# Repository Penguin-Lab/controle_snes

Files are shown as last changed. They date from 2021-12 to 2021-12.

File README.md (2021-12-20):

# controle_snes
Esse controle parecido com o de SNES (mas com analógico) foi projetado para ser usado na disciplina de Sistemas Digitais da Engenharia Elétrica. Ele envia a leitura de todos os botões e do joystick para uma FPGA de uma placa de desenvolvimento Basys 2 da Digilent. Essa comunicação é feita por UART.

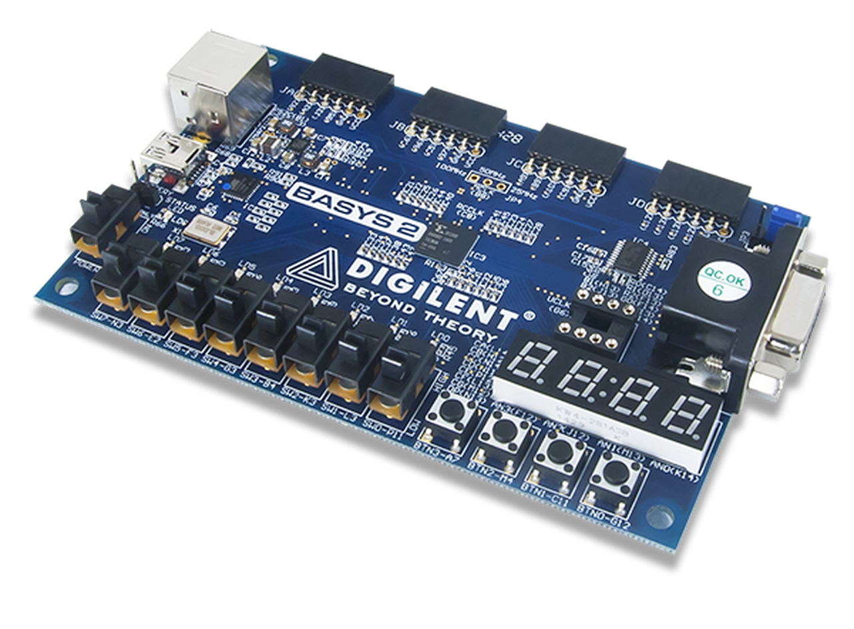
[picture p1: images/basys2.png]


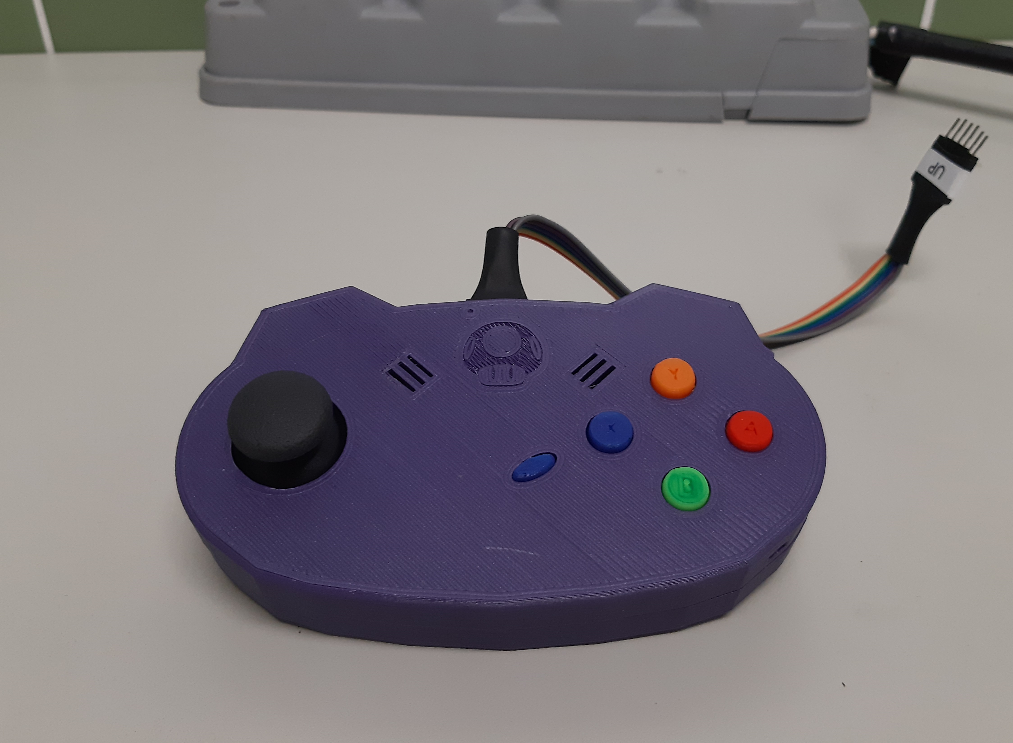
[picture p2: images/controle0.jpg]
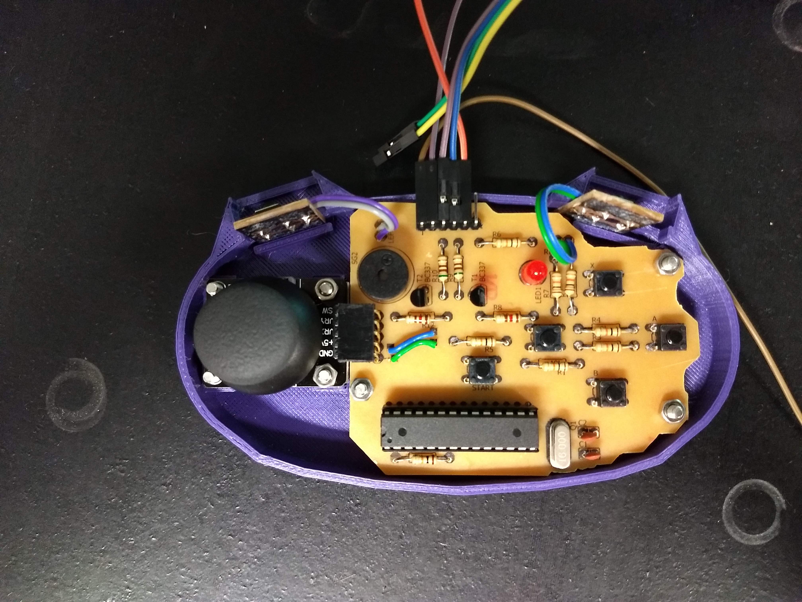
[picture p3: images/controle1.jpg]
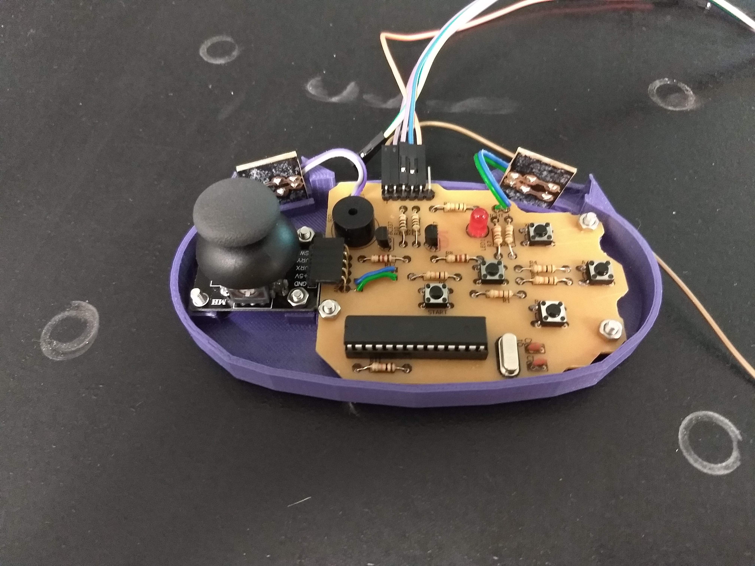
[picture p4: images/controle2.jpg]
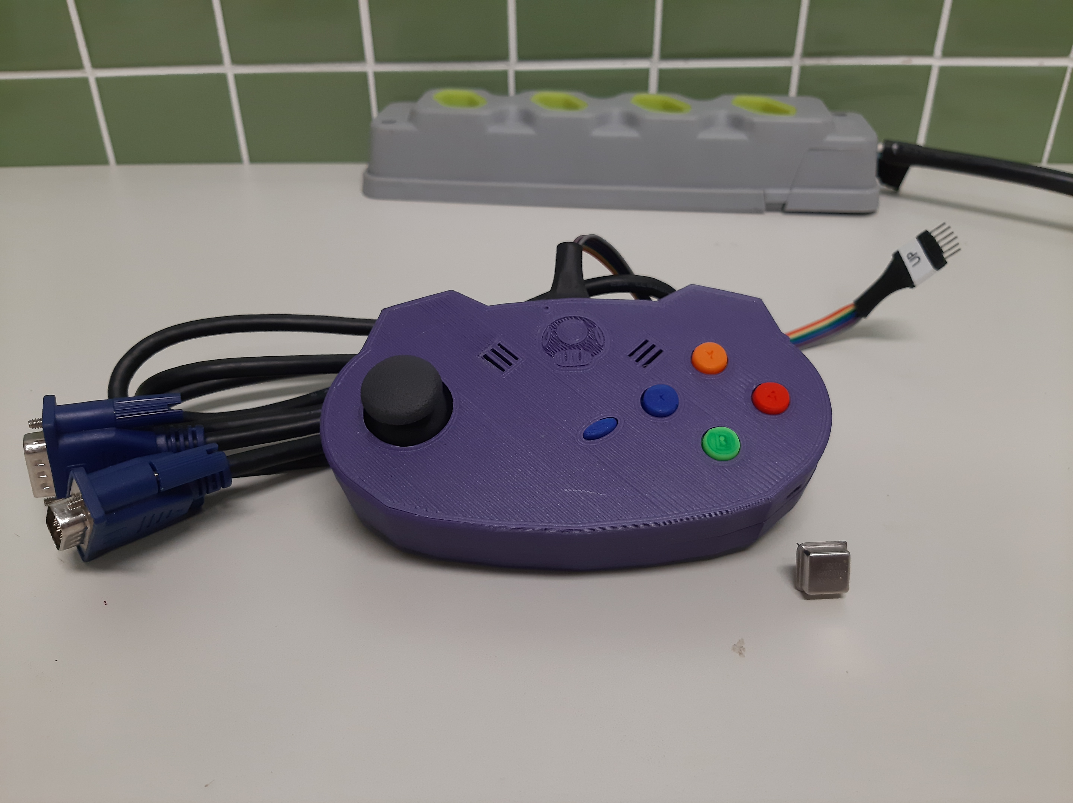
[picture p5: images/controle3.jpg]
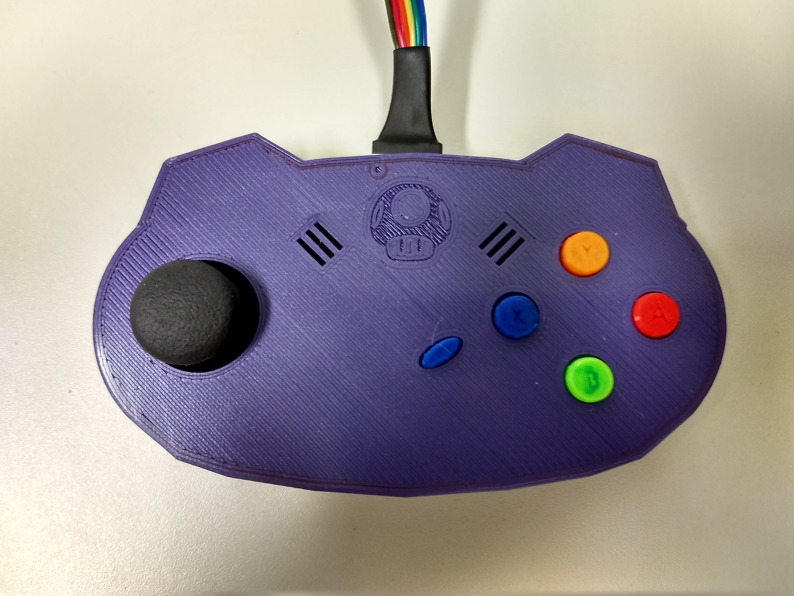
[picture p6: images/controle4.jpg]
    

Este controle foi utilizado em um trabalho para o comando de sprites do Mario Bros. em um monitor VGA.

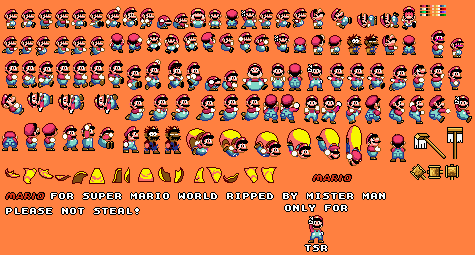
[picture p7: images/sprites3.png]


# Estrutura física
A estrutura física do controle é composta por duas peças da carcaça e 7 botões coloridos. Esse conjunto esconde a placa de circuito impresso desenvolvida e o módulo joystick.
As peças projetadas em 3D foram impressas utilizando PLA e podem ser encontradas na pasta [Pecas_3d](https://github.com/Penguin-Lab/controle_snes/tree/main/Pecas_3d) deste projeto.

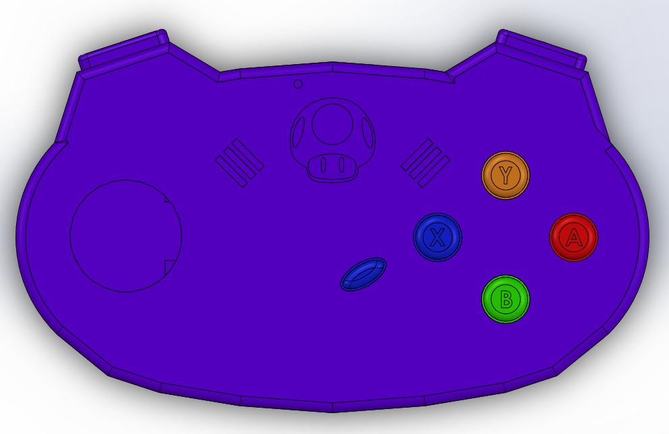
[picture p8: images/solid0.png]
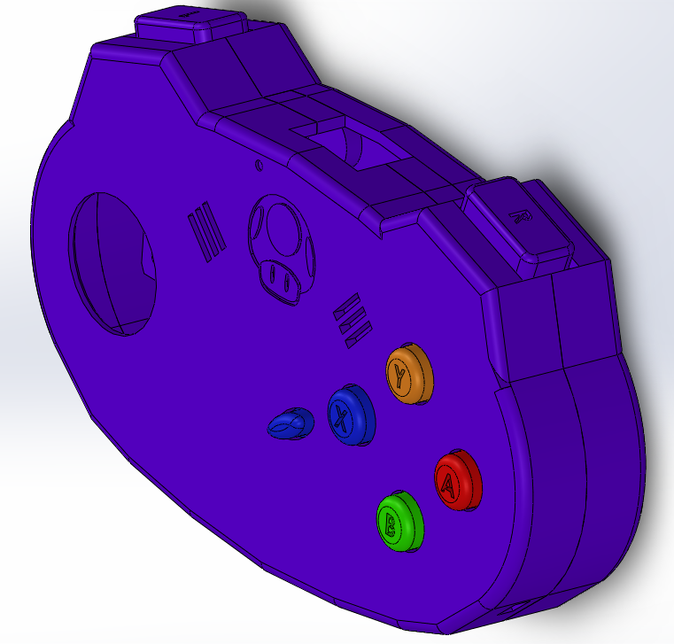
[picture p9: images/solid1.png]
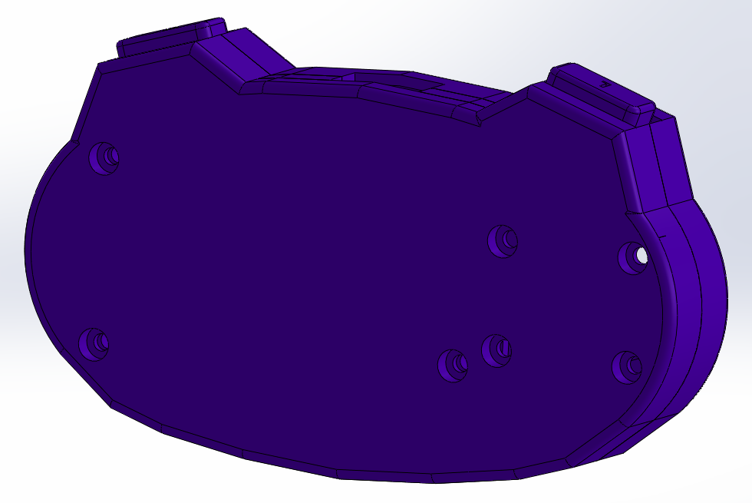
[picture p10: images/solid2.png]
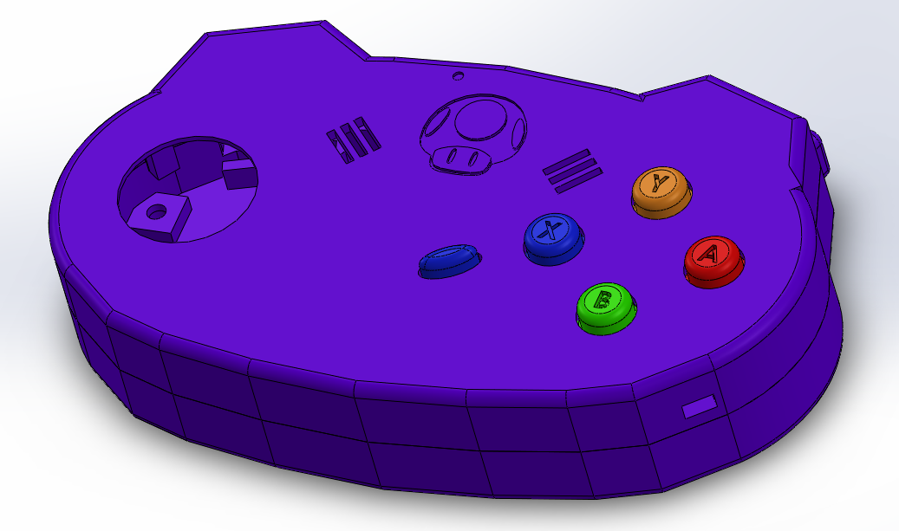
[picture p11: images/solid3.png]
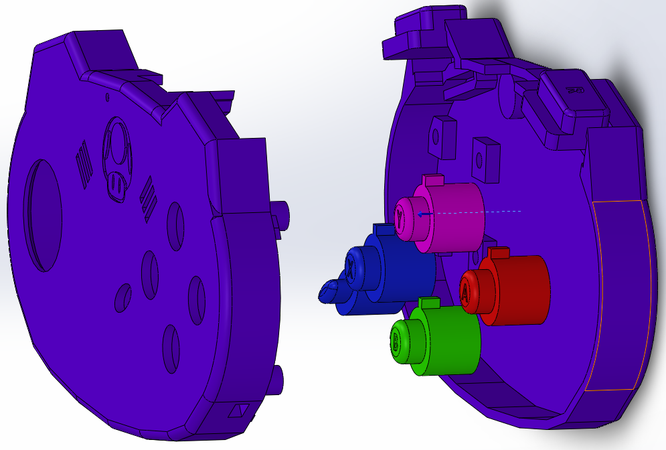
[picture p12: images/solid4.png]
    

## Placas de circuito impresso
No projeto, foi desenvolvida uma placa de circuito para que um ATMEGA328p (arduino) pudesse ler os sinais do controle e enviá-los por UART para a FPGA.

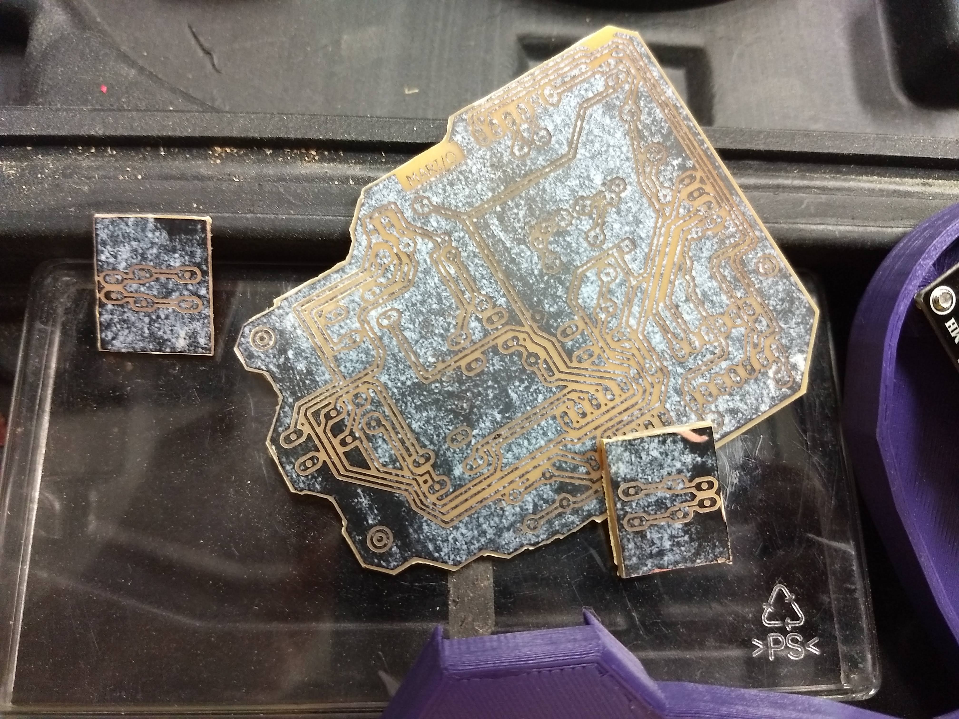
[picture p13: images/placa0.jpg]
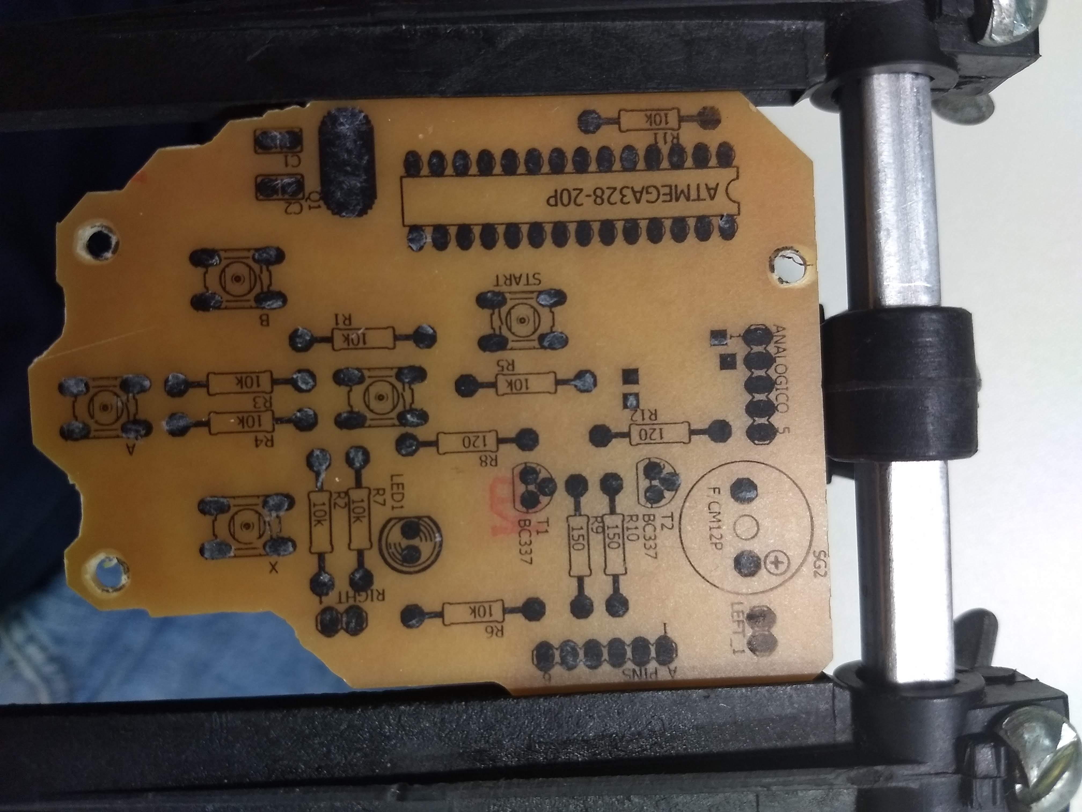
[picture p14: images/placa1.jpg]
  

O esquemático e o board do Eagle (v7.7.0) deste projeto podem ser encontrados na pasta [Placa](https://github.com/Penguin-Lab/controle_snes/tree/main/Placa). Lá também é possível encontrar o PDF para que seja impresso o projeto diretamente, sem precisar abrir o board no Eagle.

## Componentes eletrônicos
Os componentes eletrônicos utilizados para a confecção da placa são:
* 8x resistor 10k
* 2x resistor 150R
* 2x resistor 120R
* 7x push-buttons
* 1x LED vermelho 5mm
* 1x BUZZER
* 2x capacitores 22pF
* 1x cristal de clock 16MHz
* 1x soquete de 28 pinos
* 1x ATMEGA328p
* 1x módulo joystick
* 1x pinheader 6x1 macho 90 graus
* 1x pinheader 5x1 femea 90 graus

# Software
Na pasta [Codes](https://github.com/Penguin-Lab/controle_snes/tree/main/Codes), há o código de programação do arduino e da FPGA.

# Vídeo de teste
Caso queira ver um teste com o sistema funcionando, e com a implementação ainda do som do jogo sendo tocado no buzzer do controle, adicionamos um vídeo no [canal do Lab](https://www.youtube.com/channel/UCKsklKPVTsWEkaLD-hVZmng)!

Teste do controle de SNES em FPGA (https://www.youtube.com/watch?v=oQuVJGI_RX0)

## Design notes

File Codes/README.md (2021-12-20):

# Código para arduino e para FPGA
Os códigos estão separados em código para o ATMEGA328P (arduino) do controle e código em VHDL para a FPGA.

## Código do controle
O código do controle basicamente lê todos os 8 botões (7 mais o do analógico) e o joystick (analógicos vertical e horizontal), e envia via UART pelo pino RX do controle para a FPGA. Perceba que o pino se chama RX por ser o receptor da FPGA.

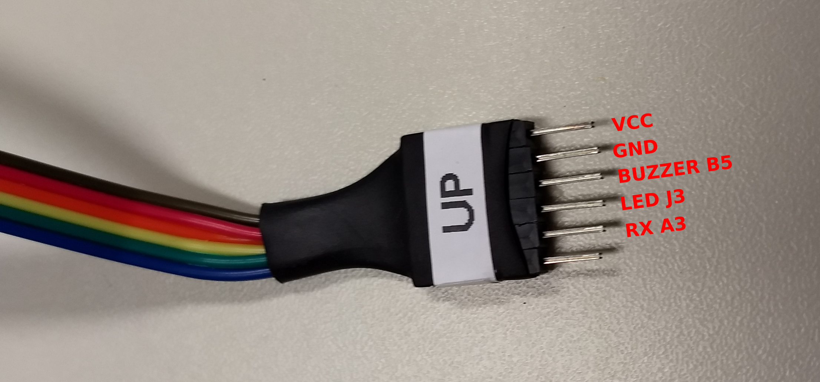
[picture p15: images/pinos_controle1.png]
  

A placa de desenvolvimento utilizada foi a Basys 2 da Digilent:



## Código da FPGA
O código em VHDL possui a seguinte estrutura:
- [marIO.vhd](https://github.com/Penguin-Lab/controle_snes/blob/main/Codes/mario_vhdl/marIO.vhd)
  - [uart_module.vhd](https://github.com/Penguin-Lab/controle_snes/blob/main/Codes/mario_vhdl/uart_module.vhd)
  - [uart_core.vhd](https://github.com/Penguin-Lab/controle_snes/blob/main/Codes/mario_vhdl/uart_core.vhd)
  - [timer.vhd](https://github.com/Penguin-Lab/controle_snes/blob/main/Codes/mario_vhdl/timer.vhd)
  - [mario_sprite.vhd](https://github.com/Penguin-Lab/controle_snes/blob/main/Codes/mario_vhdl/mario_sprite.vhd)
  - [pinmap.ucf](https://github.com/Penguin-Lab/controle_snes/blob/main/Codes/mario_vhdl/pinmap.ucf)

O bloco [marIO.vhd](https://github.com/Penguin-Lab/controle_snes/blob/main/Codes/mario_vhdl/marIO.vhd) recebe as informações via UART pelo bloco [uart_module.vhd](https://github.com/Penguin-Lab/controle_snes/blob/main/Codes/mario_vhdl/uart_module.vhd), que processa o sinal serial por meio do [uart_core.vhd](https://github.com/Penguin-Lab/controle_snes/blob/main/Codes/mario_vhdl/uart_core.vhd).

Para mostrar na tela o sprite do Mario e movimentar o personagem, temos o bloco [mario_sprite.vhd](https://github.com/Penguin-Lab/controle_snes/blob/main/Codes/mario_vhdl/mario_sprite.vhd). A velocidade de mudança do sprite e a de comunicação VGA (clock de 25MHz) são controladas por um [timer.vhd](https://github.com/Penguin-Lab/controle_snes/blob/main/Codes/mario_vhdl/timer.vhd).

Para conectar os sinais aos pinos físicos da placa, temos o [pinmap.ucf](https://github.com/Penguin-Lab/controle_snes/blob/main/Codes/mario_vhdl/pinmap.ucf).

**Obs:** para que a comunicação VGA seja estável na placa Basys 2, foi necessário adquirir um CI de clock externo (clock de 50MHz indicado pelo datasheet da placa), conectado nos pinos M6
**Obs2:** para utilizar o código em uma placa diferente, basta mapear os pinos atuais nos pinos da nova placa.

## Pinos do controle
O controle possui um conector de 6 pinos com os seguintes sinais cuja sequência segue os terminais de conexão externa da placa:



  - **VCC**: alimentação do controle
  - **GND**: referência
  - **BUZZER**: pino B5 sendo saída da FPGA para comandar o buzzer do controle
  - **LED**: pino J3 sendo saída da FPGA para comandar o LED do controle
  - **RX**: pino A3 sendo entrada da FPGA para receber os dados de leitura do controle de SNES
  - **N/C**: pino sem conexão

## Leitura dos botões do controle
O controle lê por meio do ATMEGA328p o estado de todos os botões e analógicos e envia por UART para a FPGA quatro dados de 8 bits no formato:

  - **data1**: "00" & **X** & **Y** & **B** & **A** & **L** & **R**
  - **data2**: "01" & **start** & **bt** & **Ax(7 downto 4)**
  - **data3**: "10" & **Ax(3 downto 0)** & **Ay(7 downto 6)**
  - **data4**: "11" & **Ay(5 downto 0)**

Sendo, **bt** o botão do joystick.

Assim que o [uart_module.vhd](https://github.com/Penguin-Lab/controle_snes/blob/main/Codes/mario_vhdl/uart_module.vhd) recebe todos os quatro dados de 8 bits, ele avisa ao [marIO.vhd](https://github.com/Penguin-Lab/controle_snes/blob/main/Codes/mario_vhdl/marIO.vhd) que os dados novos estão disponíveis colocando o sinal **validData** em '1'.

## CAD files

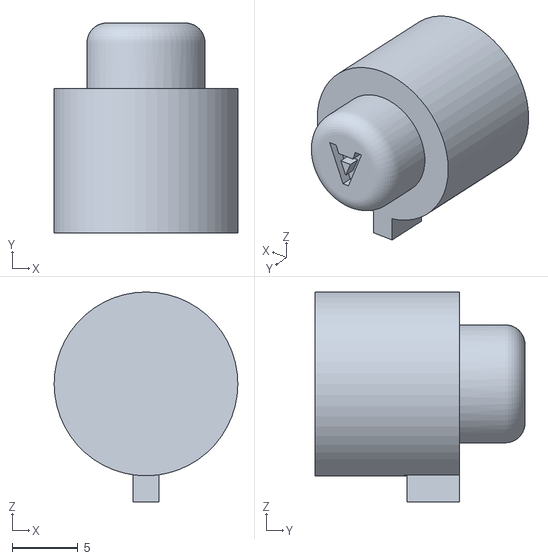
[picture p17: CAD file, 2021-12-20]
Pecas_3d/Controle_BOTAO_A.STL
14.0 x 16.0 x 16.0

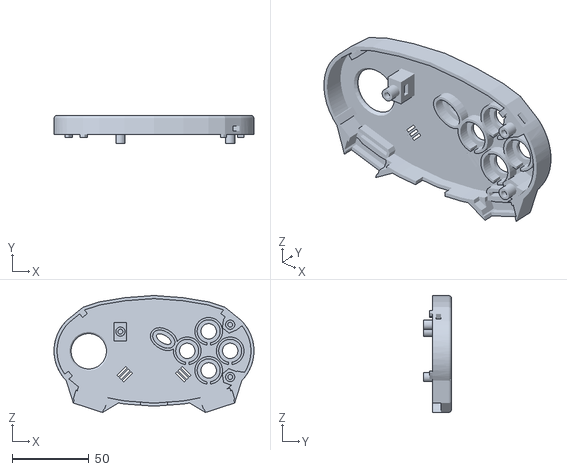
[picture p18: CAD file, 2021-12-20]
Pecas_3d/Controle_FRENTE.STL
130.0 x 18.4 x 76.1

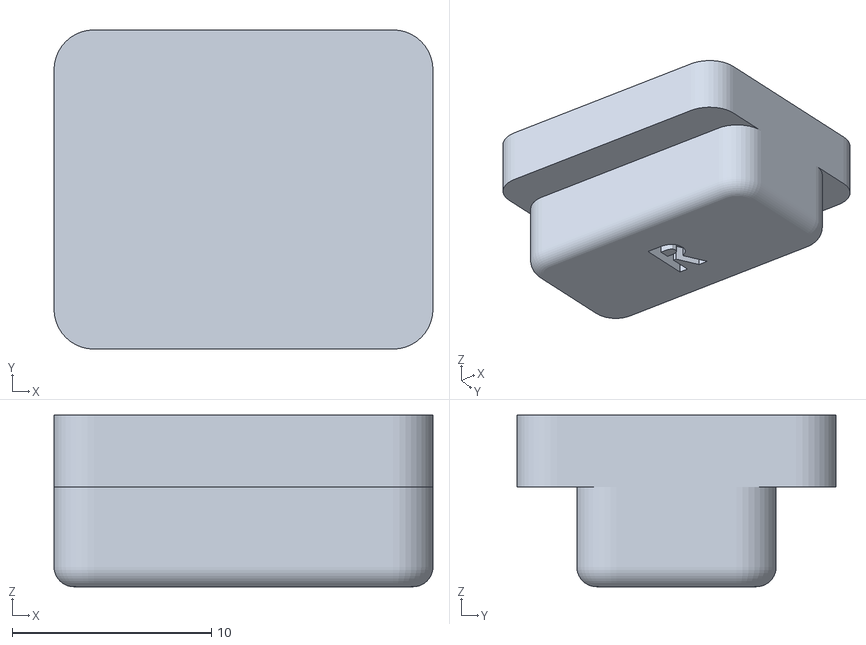
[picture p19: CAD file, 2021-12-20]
Pecas_3d/Controle_BOTAO_R.STL
19.0 x 16.0 x 8.60

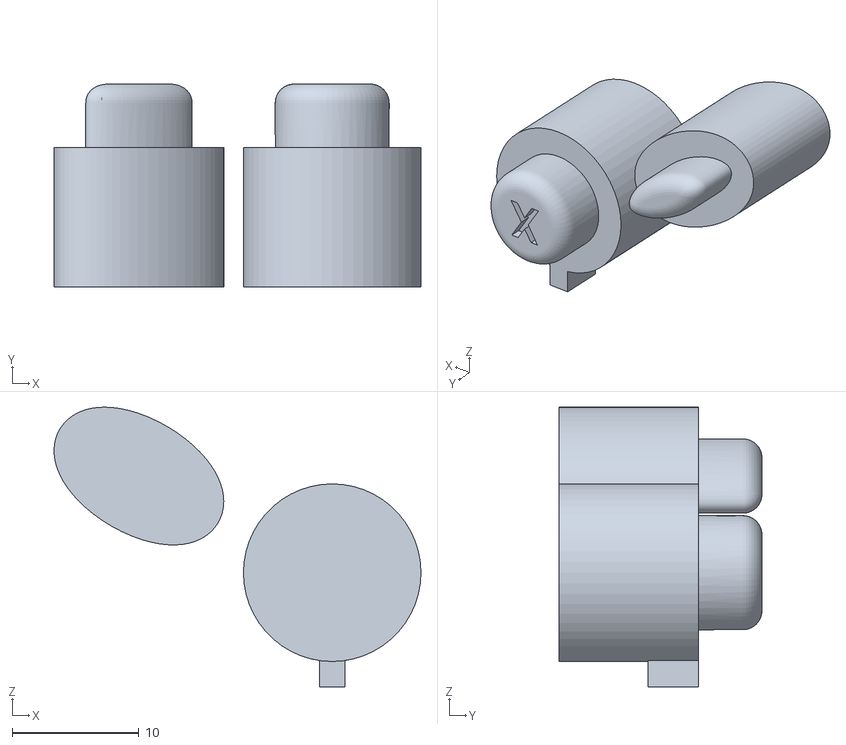
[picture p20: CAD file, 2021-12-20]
Pecas_3d/Controle_BOTAO_X_START.STL
28.9 x 16.0 x 22.1

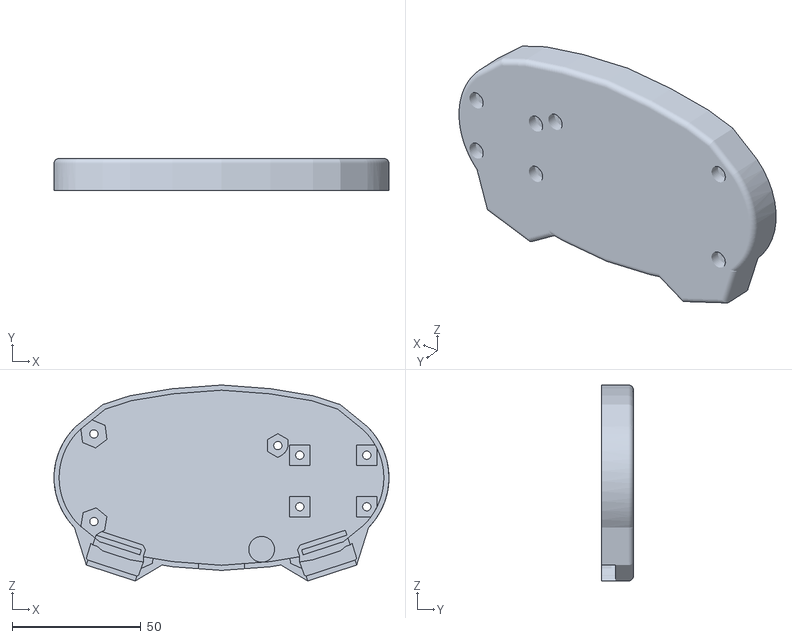
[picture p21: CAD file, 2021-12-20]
Pecas_3d/Controle_TRAS.STL
130.0 x 12.5 x 76.1

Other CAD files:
Pecas_3d/Controle_BOTAO_Y.STL
Pecas_3d/Controle_BOTAO_B.STL
Pecas_3d/Controle_BOTAO_L.STL

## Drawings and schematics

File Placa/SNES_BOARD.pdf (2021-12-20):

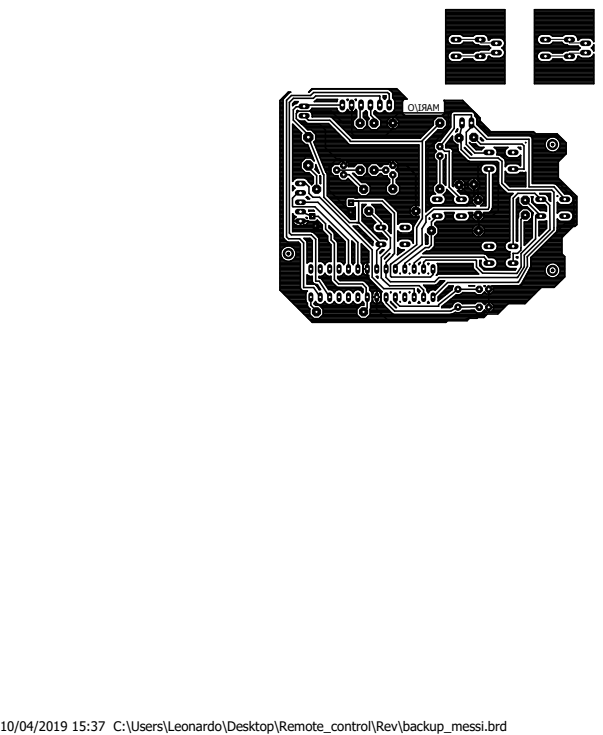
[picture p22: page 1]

10/04/2019 15:37 C:\Users\Leonardo\Desktop\Remote_control\Rev\backup_messi.brd

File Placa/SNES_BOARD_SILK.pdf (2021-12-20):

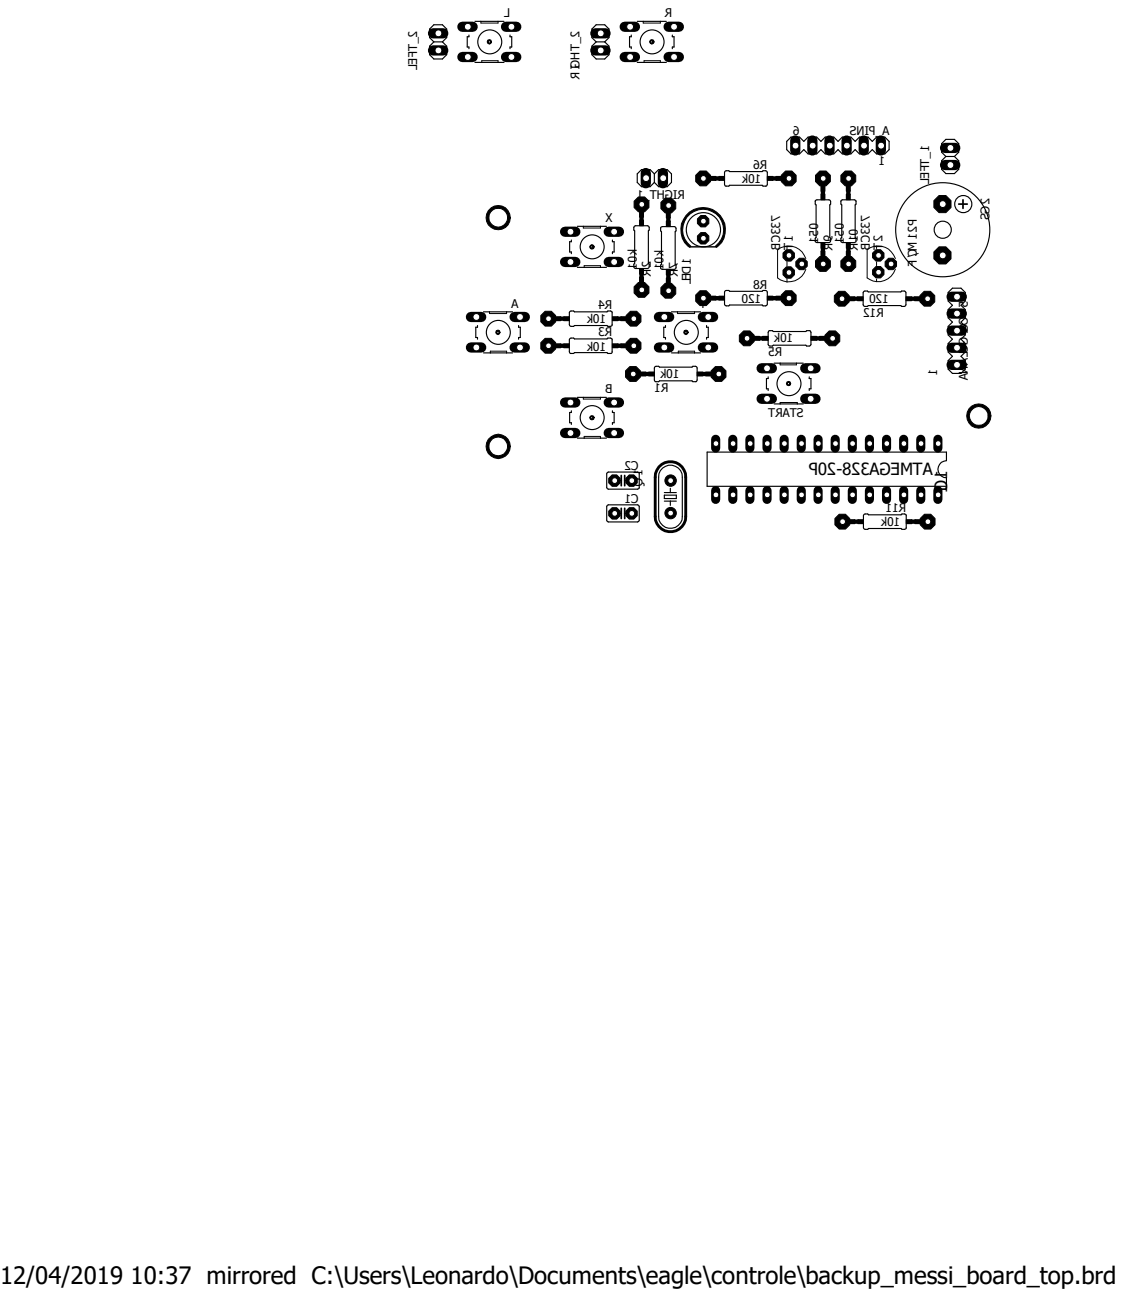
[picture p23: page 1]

12/04/2019 10:37 mirrored C:\Users\Leonardo\Documents\eagle\controle\backup_messi_board_top.brd

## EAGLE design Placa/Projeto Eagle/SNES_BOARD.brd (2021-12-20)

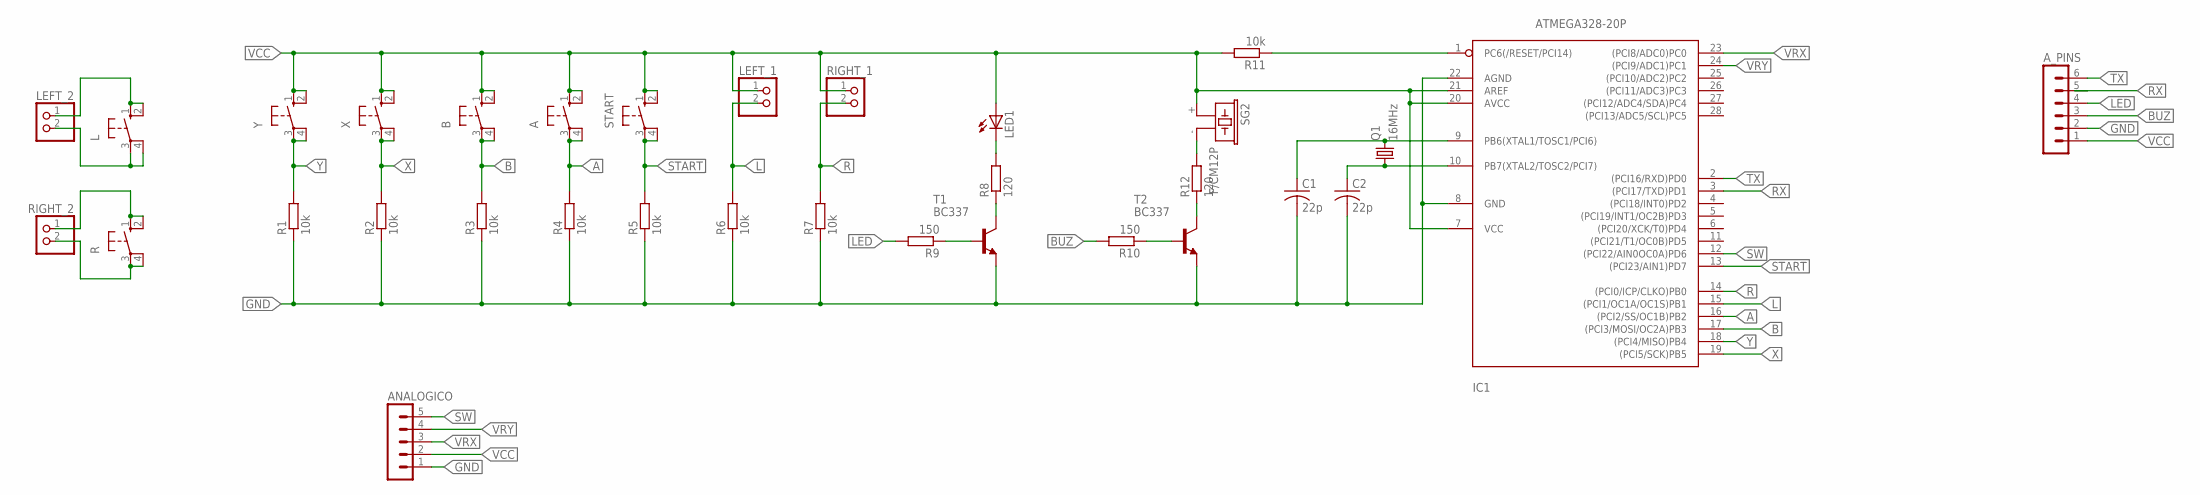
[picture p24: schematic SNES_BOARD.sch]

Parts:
A: 10-XX; B3F-10XX
ANALOGICO: MA05-1
A_PINS: MA06-1
B: 10-XX; B3F-10XX
C1, C2: 22p; C025-025X050
IC1: ATMEGA328-20P; DIL28-3
L: 10-XX; B3F-10XX
LED1: LED5MM
LEFT_1, LEFT_2: PINHD-1X2; 1X02
Q1: 16MHz; HC49U-V
R: 10-XX; B3F-10XX
R1, R2, R3, R4, R5, R6, R7, R11: 10k; 0207/12
R8, R12: 120; 0207/12
R9, R10: 150; 0207/12
RIGHT_1, RIGHT_2: PINHD-1X2; 1X02
SG2: F/CM12P
START: 10-XX; B3F-10XX
T1, T2: BC337; TO92
X: 10-XX; B3F-10XX
Y: 10-XX; B3F-10XX

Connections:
A: A.3, A.4 (P1), IC1.16 ((PCI2/SS/OC1B)PB2), R4.2
B: B.3, B.4 (P1), IC1.17 ((PCI3/MOSI/OC2A)PB3), R3.2
BUZ: A_PINS.3, R10.2
GND: ANALOGICO.1, A_PINS.2, C1.2, C2.2, IC1.8 (GND), IC1.22 (AGND), R1.1, R2.1, R3.1, R4.1, R5.1, R6.1, R7.1, T1.1 (E), T2.1 (E)
L: IC1.15 ((PCI1/OC1A/OC1S)PB1), LEFT_1.2, R6.2
LED: A_PINS.4, R9.2
unnamed: LED1.K (C), R8.2
unnamed: L.1 (S), L.2 (S1), LEFT_2.1
unnamed: L.3, L.4 (P1), LEFT_2.2
unnamed: R.1 (S), R.2 (S1), RIGHT_2.1
unnamed: R.3, R.4 (P1), RIGHT_2.2
unnamed: R8.1, T1.3 (C)
unnamed: R9.1, T1.2 (B)
unnamed: R12.2, SG2.- (2)
unnamed: R10.1, T2.2 (B)
unnamed: IC1.1 (PC6(/RESET/PCI14)), R11.1
unnamed: C1.1, IC1.9 (PB6(XTAL1/TOSC1/PCI6)), Q1.2
unnamed: C2.1, IC1.10 (PB7(XTAL2/TOSC2/PCI7)), Q1.1
unnamed: R12.1, T2.3 (C)
R: IC1.14 ((PCI0/ICP/CLKO)PB0), R7.2, RIGHT_1.2
RX: A_PINS.5, IC1.3 ((PCI17/TXD)PD1)
START: IC1.13 ((PCI23/AIN1)PD7), R5.2, START.3, START.4 (P1)
SW: ANALOGICO.5, IC1.12 ((PCI22/AIN0OC0A)PD6)
TX: A_PINS.6, IC1.2 ((PCI16/RXD)PD0)
VCC: A.1 (S), A.2 (S1), ANALOGICO.2, A_PINS.1, B.1 (S), B.2 (S1), IC1.7 (VCC), IC1.20 (AVCC), IC1.21 (AREF), LED1.A, LEFT_1.1, R11.2, RIGHT_1.1, SG2.+ (1), START.1 (S), START.2 (S1), X.1 (S), X.2 (S1), Y.1 (S), Y.2 (S1)
VRX: ANALOGICO.3, IC1.23 ((PCI8/ADC0)PC0)
VRY: ANALOGICO.4, IC1.24 ((PCI9/ADC1)PC1)
X: IC1.19 ((PCI5/SCK)PB5), R2.2, X.3, X.4 (P1)
Y: IC1.18 ((PCI4/MISO)PB4), R1.2, Y.3, Y.4 (P1)

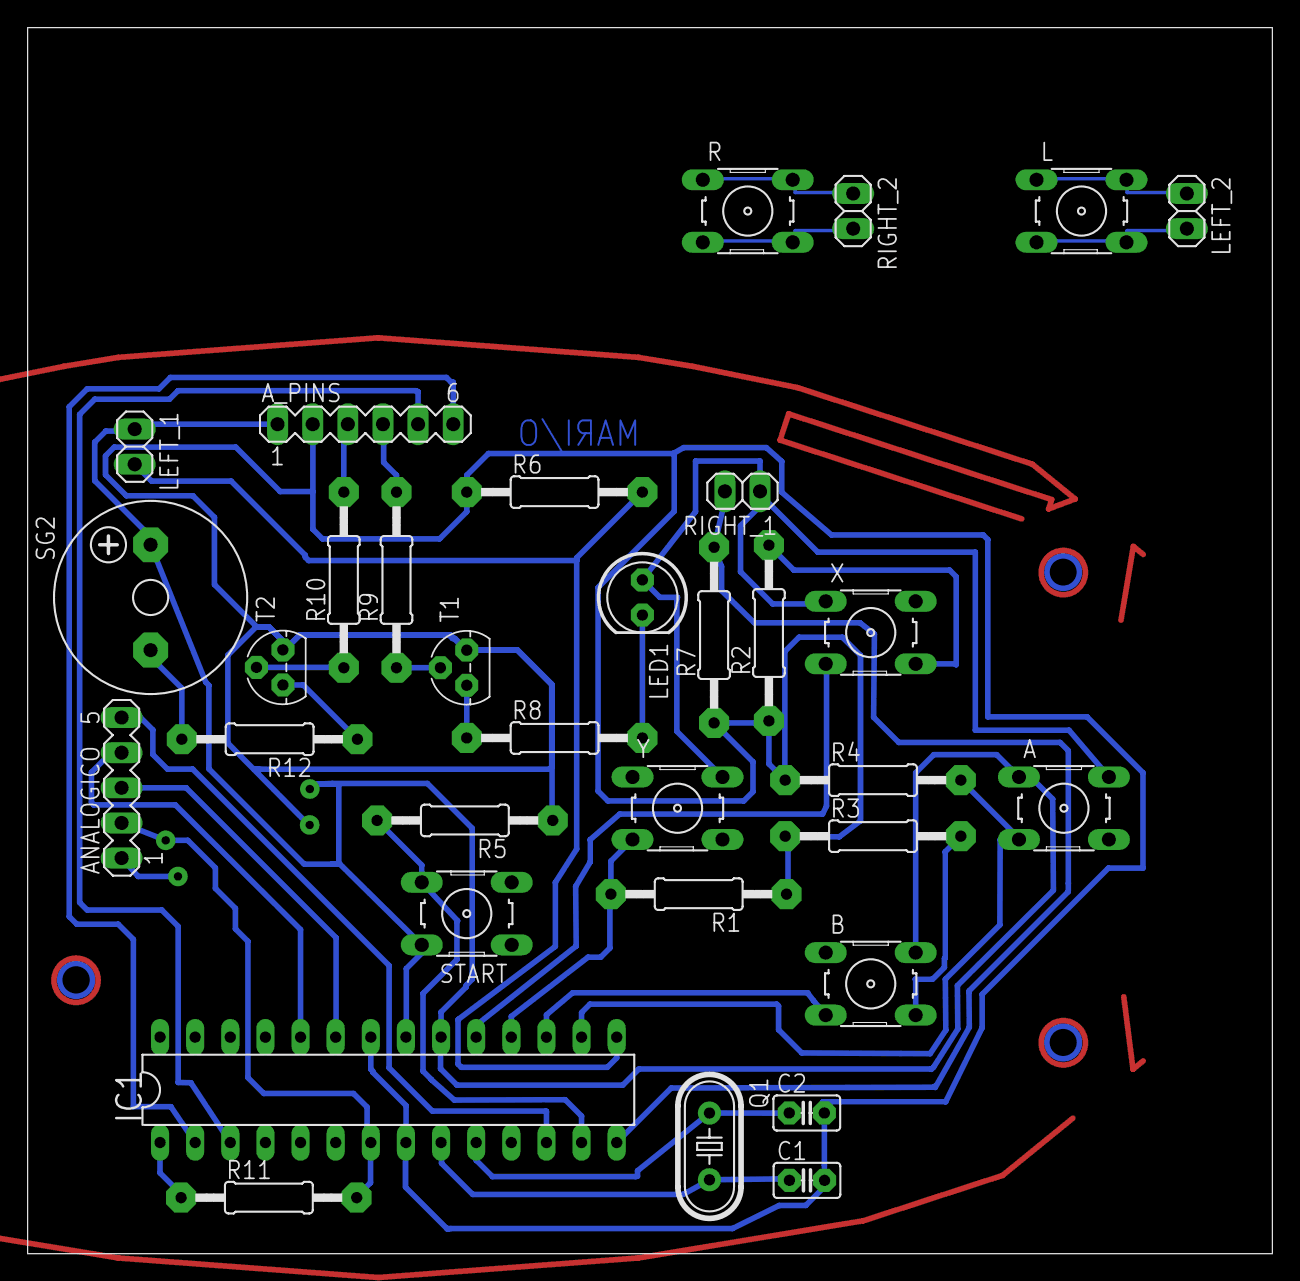
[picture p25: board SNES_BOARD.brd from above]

Board: 2 copper layers, 90.0 x 88.7 mm, 33 parts (0 on the bottom side), 29 nets.

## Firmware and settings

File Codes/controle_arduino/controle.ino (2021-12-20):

// Outputs:
byte data1 =   0; //0b00000000 -> 0b00 X Y B A L R
byte data2 =  64; //0b01000000 -> 0b01 S Bt Ax(4bitsH)
byte data3 = 128; //0b10000000 -> 0b10 Ax(4bitsL) Ay(2bitsH)
byte data4 = 192; //0b11000000 -> 0b11 Ay(6bitsL)

// Inputs:
bool X,Y,B,A,L,R,S,Bt;
byte Ax,Ay;

void setup() {
  Serial.begin(9600);
  pinMode(13, INPUT); // X
  pinMode(12, INPUT); // Y
  pinMode(11, INPUT); // B
  pinMode(10, INPUT); // A
  pinMode(9, INPUT); // L
  pinMode(8, INPUT); // R

  pinMode(7, INPUT); // S
  pinMode(6, INPUT); // Bt

  // A0 = Ax
  // A1 = Ay
}

void loop() {
  // Read the sensors:
  X = digitalRead(13);
  Y = digitalRead(12);
  B = digitalRead(11);
  A = digitalRead(10);
  L = digitalRead(9);
  R = digitalRead(8);

  S = digitalRead(7);
  Bt = digitalRead(6);

  Ax = map(analogRead(A0),0,1023,0,255);
  Ay = map(analogRead(A1),0,1023,0,255);
  
  /*
  // Example:
  X = true;
  Y = false;
  B = false;
  A = true;
  L = true;
  R = false;

  S = true;
  Bt = false;

  Ax = 0b01110101;
  Ay = 0b10101101;
  */
  
  // Preparing data:
  data1 = 0 + (X<<5) + (Y<<4) + (B<<3) + (A<<2) + (L<<1) + R; //0b00000000 -> 0b00 X Y B A L R
  data2 = (0b01000000) + (S<<5) + (Bt<<4) + (Ax>>4); //0b01000000 -> 0b01 S Bt Ax(4bitsH)
  byte Axaux = Ax-((Ax>>4)<<4);
  data3 = (0b10000000) + (Axaux<<2) + (Ay>>6); //0b10000000 -> 0b10 Ax(4bitsL) Ay(2bitsH)
  byte Ayaux = Ay-((Ay>>6)<<6);
  data4 = (0b11000000) + Ayaux; //0b11000000 -> 0b11 Ay(6bitsL)
    
  // Send the data - uart:
  Serial.write(data1); //data1
  _delay_us(400);
  Serial.write(data2); //data2
  _delay_us(400);
  Serial.write(data3); //data3
  _delay_us(400);
  Serial.write(data4); //data4
  _delay_us(400);
}

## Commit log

2021-12-20 Add files via upload
    peças 3d do controle
    [Controle_BOTAO_A.STL, Controle_BOTAO_B.STL, Controle_BOTAO_L.STL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]
2021-12-20 Add files via upload
    código para vhdl (basys 2) e arduino (controle)
2021-12-20 Add files via upload
    esquemático, board e arquivos pdf da placa
    [SNES_BOARD.brd, SNES_BOARD.sch]
